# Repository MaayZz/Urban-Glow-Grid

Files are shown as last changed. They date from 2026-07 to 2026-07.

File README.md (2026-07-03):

# 🗼 Urban Glow Grid — Project Documentation

Welcome to the official repository of **Urban Glow Grid** (Team 22). This project was created to fight **"Energy Blindness"** — the invisible nature of our daily energy consumption. 

Urban Glow Grid is a **physical, interactive 1:15,000 scale model of Paris** that gamifies electrical grid management. Players act as Chief Engineers, physically manipulating dials and switches to balance grid loads, prevent blackouts, and learn key sustainable energy principles in real-time.

---

## 📸 Mockup & Hardware Overview

Below is the visual structure of the physical prototype and the challenges encountered during fabrication:

* **Paris Scale Model (Overview)**: Physical wood model split into 6 key energy zones with 3D-printed translucent landmarks (Eiffel Tower, Louvre, Arc de Triomphe) diffusing NeoPixel LED light.
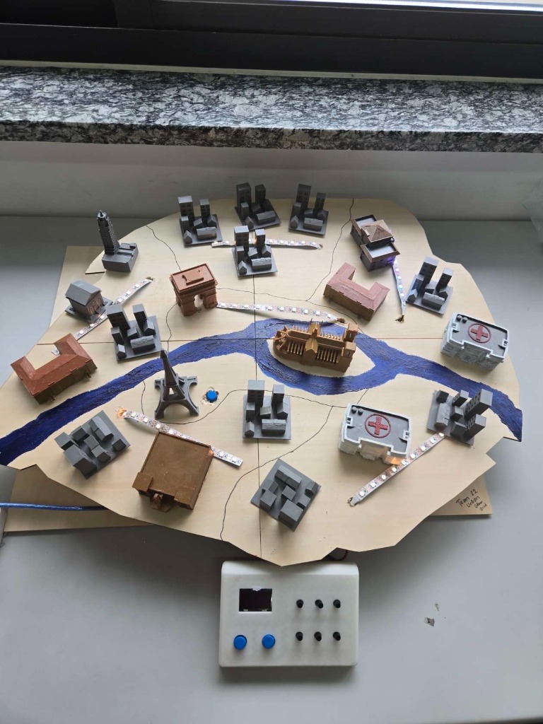
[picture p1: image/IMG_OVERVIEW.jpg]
Paris Scale Model Overview
  
* **Wiring Under the Hood (Challenges)**: A look at the electronics layer managing nearly 90 jumper wires, showing the physical complexity and loose connections we resolved by separating structural components from the circuitry.
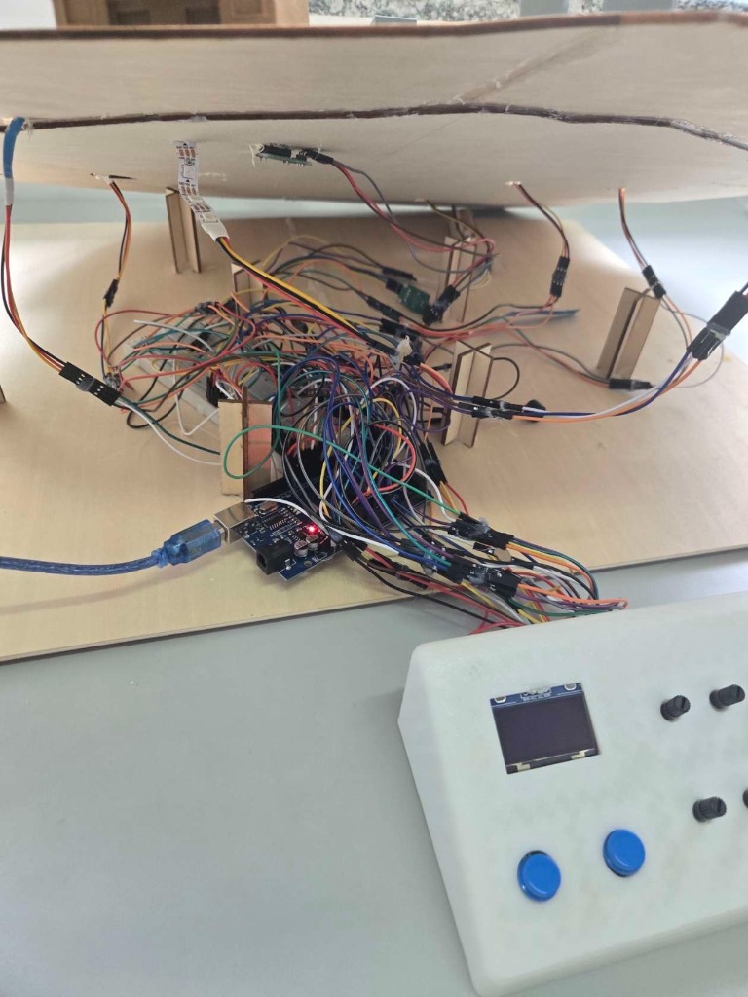
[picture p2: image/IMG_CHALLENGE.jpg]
Wiring Infrastructure Challenges
  

---

## 📂 Repository Directory Structure

To help future developers take over and scale this project, here is how the files are organized:

* `arduino/`
  * `urban_glow_grid_mega_final/`: The production code uploaded to the Arduino Mega managing inputs/outputs.
  * `mega_hardware_test/`: Simple test scripts to isolate issues with OLED, LEDs, dials, or buttons.
  * `arduino_wiring.md`: Detailed pinout mapping and electronic connection guide.
  * `wiring_guide.pdf`: Blueprints showing the circuit layout.
* `image/`: Clean folder containing project photos.

---

## 🛠 Hardware Architecture & Bill of Materials (BOM)

The physical maquette separates the **wooden layout structure** from the **electronics layer** to allow easy, non-destructive wiring iterations. 

### Key Components:
1. **Microcontroller**: Arduino Mega 2560 (selected for its high pin count to drive multiple parallel sensors/LEDs).
2. **Visual Indicators**: 6 WS2812B NeoPixel strips (underneath landmarks) + I2C SSD1306 OLED Display (shows real-time numeric load metrics).
3. **Control Interface**: 6 Potentiometers (load balancing dials) + 4 tactile Push Buttons (priority building toggles) + 1 Master Reset Button.
4. **Audio Feedback**: 8-ohm Speaker/Buzzer (emits blackout warning alarms).
5. **Physical Enclosure**: Laser-cut plywood baseboard, translucent PLA 3D-printed landmarks.

### Sourcing & Cost Breakdown (Strictly < 200 RMB)

| Component | Qty | Function | Est. Cost (RMB) |
| :--- | :---: | :--- | :---: |
| **Arduino Mega 2560** | 1 | Central Processing Unit | 45.00 |
| **WS2812B LED Strips** | 6 | Paris Zone status lights (Green/Red) | 30.00 |
| **OLED Display (I2C SSD1306)** | 1 | Real-time system display screen | 15.00 |
| **Potentiometers (Dials)** | 6 | Local load adjustment controls | 12.00 |
| **Push Buttons (Toggles)** | 4 | Priority building power overrides | 4.00 |
| **Speaker / Buzzer** | 1 | Audio blackout alarms | 5.00 |
| **Physical Materials** | — | Laser-cut plywood, 3D printing PLA, glue, screws | 80.00 |
| **TOTAL** | | | **~191.00 RMB** |

---

## 💻 Software Setup & Installation

### Arduino Code Deployment
Open the production code (`arduino/urban_glow_grid_mega_final/urban_glow_grid_mega_final.ino`) in the Arduino IDE. 

Make sure you have installed the following libraries via the Arduino Library Manager:
* **Adafruit_NeoPixel** (to control the WS2812B LEDs)
* **SSD1306Ascii** (lightweight text-only library to control the OLED screen without overloading SRAM)

Compile and upload the project onto your Arduino Mega.

---

## 🕹 Game Rules & Playbook

The game simulates a peak winter day. The player has **3 minutes** to maintain the stability of the Paris electrical grid.

1. **Balance the Grid**: Dials (potentiometers) represent zone power. When a zone turns **red** (overloaded), you must rotate the dial to decrease non-essential load.
2. **Prioritize Buildings**: Tactile buttons allow you to route power away from residential blocks to vital sectors (like hospitals or water systems) during heavy strain.
3. **Avoid Blackout**: The OLED screen shows total system capacity. If the total load exceeds 95%, the buzzer sounds a warning. If it hits 100% for more than 5 consecutive seconds, a **Blackout** is triggered: all LEDs flash red, the game resets, and you lose.
4. **Victory Condition**: Maintain system stability until the timer expires.

---

## 🚀 Future Roadmap & Developer Notes

If you are resuming this project, here are the critical steps required to turn this prototype into a commercial product:

* **Transition to Custom PCB**: The biggest hardware challenge was **Loose Connections** (wires coming loose from the breadboards due to physical vibration). Designing a dedicated Printed Circuit Board (PCB) to replace jumper wires will reduce assembly time by 95% and make the product robust enough for shipping.
* **Scale Software Architecture**: The current C++ simulation is optimized for Paris (6 zones). The code is structured modularly so you can swap out the geographic layout files and LED indices to model other cities.
* **Transition to B2B Educational Kits**: The low BOM (< 200 RMB) makes this highly profitable. Next phases should package the PCB, components, and a flat-packed wooden box as a "build-your-own smart city kit" for EdTech classrooms.

---

## 👥 Roles & Organization (Team 22)
* **CEO / Project Lead**
* **CTO / System Architecture**
* **Creative Director**
* **Hardware & Fabrication Support**

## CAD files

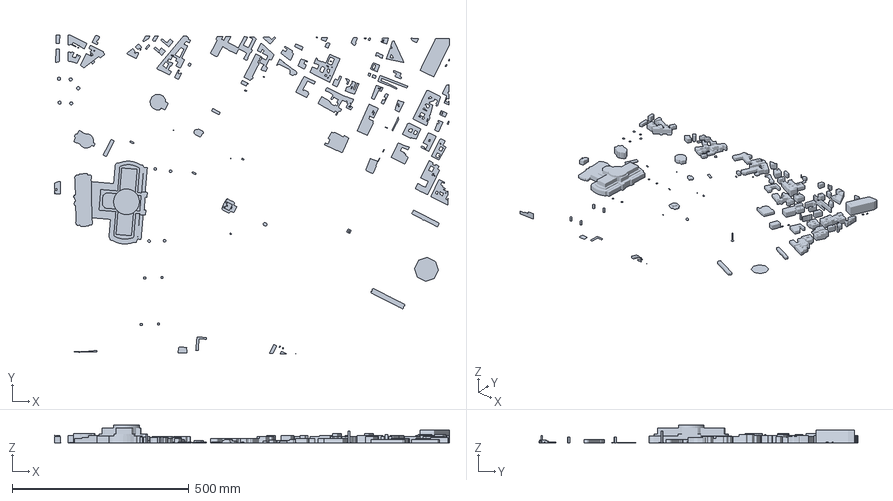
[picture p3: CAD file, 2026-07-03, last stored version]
simulation/cadmapper-paris-ile-de-france-fr.dxf
1118.6 x 903.1 x 50.0 mm

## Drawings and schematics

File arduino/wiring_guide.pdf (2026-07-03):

# Urban Glow Grid

Visualisation 3D photoréaliste du montage sur deux breadboards.

### 1. Organisation Générale des Composants

Le montage est réparti sur deux plaques d'essai (breadboards) afin de bien isoler la partie commande (basse puissance) de la partie alimentation des bandes LED (haute puissance). Cette séparation est essentielle pour éviter les parasites sur les signaux analogiques et garantir un fonctionnement stable.

Plaque d'Essai n°1 : Logique et Contrôle

MCP3008 (ADC SPI) : Placé au centre. Il reçoit les fils des 6 potentiomètres.

Guide de Câblage Visuel Officiel – Prototype Simplifié (1 Arduino Uno)

6 Potentiomètres : Alimentés en 5V et reliés aux canaux CH0 à CH5 du MCP3008.

5 Boutons Poussoirs : Câblés en direct vers l'Arduino avec la résistance interne INPUT_PULLUP.

Écran OLED SSD1306 : Relié au bus I2C matériel de l'Arduino (A4/A5).

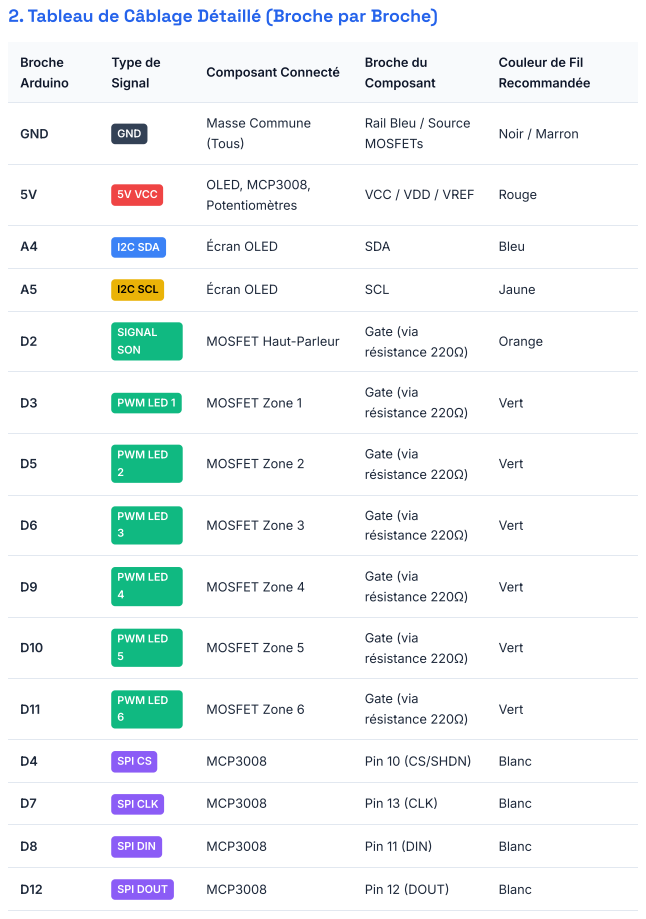
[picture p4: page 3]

2. Tableau de Câblage Détaillé (Broche par Broche)

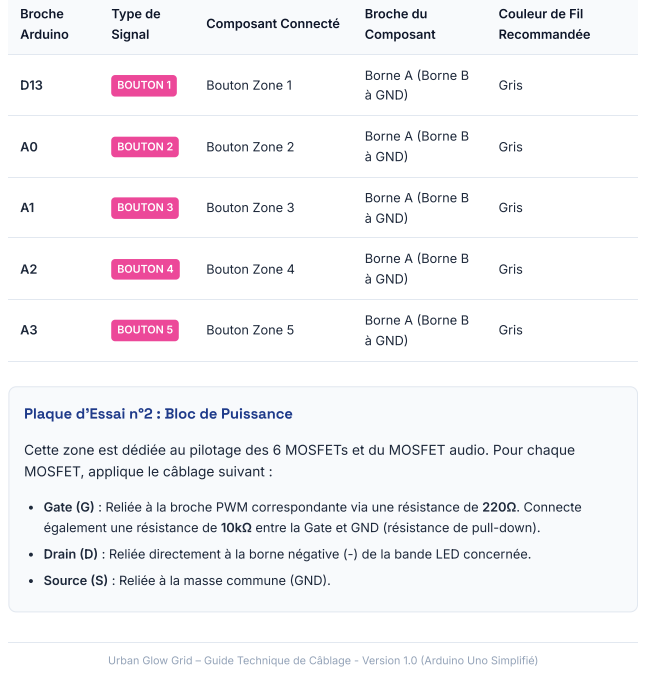
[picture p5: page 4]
Broche Arduino; Type de Signal; Composant Connecté; Broche du Composant; BOUTON 1; Bouton Zone 1; Borne A (Borne B à GND); Gris; BOUTON 2; Bouton Zone 2; BOUTON 3; Bouton Zone 3; BOUTON 4; Bouton Zone 4; BOUTON 5; Bouton Zone 5

Couleur de Fil
Recommandée

Plaque d'Essai n°2 : Bloc de Puissance

Cette zone est dédiée au pilotage des 6 MOSFETs et du MOSFET audio. Pour chaque
MOSFET, applique le câblage suivant :

Gate (G) : Reliée à la broche PWM correspondante via une résistance de 220Ω. Connecte
également une résistance de 10kΩ entre la Gate et GND (résistance de pull-down).
Drain (D) : Reliée directement à la borne négative (-) de la bande LED concernée.
Source (S) : Reliée à la masse commune (GND).

Urban Glow Grid – Guide Technique de Câblage - Version 1.0 (Arduino Uno Simplifié)

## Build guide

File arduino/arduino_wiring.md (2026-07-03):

# 🔌 Guide de Câblage & Configuration des Pins — Arduino Mega 2560

Ce document décrit les connexions électriques réelles utilisées sur le prototype physique final de **Urban Glow Grid**. Les affectations ci-dessous correspondent exactement aux définitions du code de production final (`arduino/urban_glow_grid_mega_final/urban_glow_grid_mega_final.ino`).

---

## 🎛 Tableau de Câblage Complet

| Composant Physique | Type de Signal | Pin Arduino | Mode Pin | Description |
| :--- | :--- | :--- | :--- | :--- |
| Écran OLED (1.3 pouce) | I2C (SDA / SCL) | **SDA** -> Broche D20 <br> **SCL** -> Broche D21 | Entrée / Sortie | Liaison I2C pour l'affichage de l'état du réseau |
| Potentiomètre 1 | Entrée Analogue | A0 | INPUT | Réglage de charge de la Zone 1 |
| Potentiomètre 2 | Entrée Analogue | A1 | INPUT | Réglage de charge de la Zone 2 |
| Potentiomètre 3 | Entrée Analogue | A2 | INPUT | Réglage de charge de la Zone 3 |
| Potentiomètre 4 | Entrée Analogue | A3 | INPUT | Réglage de charge de la Zone 4 |
| Potentiomètre 5 | Entrée Analogue | A4 | INPUT | Réglage de charge de la Zone 5 |
| Potentiomètre 6 | Entrée Analogue | A5 | INPUT | Réglage de charge de la Zone 6 |
| Ruban LED 17cm (Zone 1) | Sortie Digitale | Broche 2 | OUTPUT | Indicateur LED de la Zone 1 |
| Ruban LED 17cm (Zone 2) | Sortie Digitale | Broche 3 | OUTPUT | Indicateur LED de la Zone 2 |
| Ruban LED 17cm (Zone 3) | Sortie Digitale | Broche 4 | OUTPUT | Indicateur LED de la Zone 3 |
| Ruban LED 17cm (Zone 4) | Sortie Digitale | Broche 5 | OUTPUT | Indicateur LED de la Zone 4 |
| Ruban LED 17cm (Zone 5) | Sortie Digitale | Broche 6 | OUTPUT | Indicateur LED de la Zone 5 |
| Ruban LED 17cm (Zone 6) | Sortie Digitale | Broche 7 | OUTPUT | Indicateur LED de la Zone 6 |
| Ruban LED 10cm (Mon. 1) | Sortie Digitale | Broche 8 | OUTPUT | Indicateur LED du Monument 1 |
| Ruban LED 10cm (Mon. 2) | Sortie Digitale | Broche 9 | OUTPUT | Indicateur LED du Monument 2 |
| Speaker 1 | Sortie PWM | Broche 22 | OUTPUT | Haut-parleur principal (Sons système et sirènes d'alarme) |
| Speaker 2 | Sortie PWM | Broche 24 | OUTPUT | Haut-parleur secondaire (Bruits de clic / battement de cœur) |
| Bouton 1 (Start) | Entrée Digitale | Broche 26 | INPUT_PULLUP | Bouton poussoir pour lancer la partie |
| Bouton 2 (Reset) | Entrée Digitale | Broche 28 | INPUT_PULLUP | Bouton poussoir pour réinitialiser le jeu |
| Bouton 3 (Monument 1) | Entrée Digitale | Broche 30 | INPUT_PULLUP | Bouton pour activer/désactiver le Monument 1 |
| Bouton 4 (Monument 2) | Entrée Digitale | Broche 32 | INPUT_PULLUP | Bouton pour activer/désactiver le Monument 2 |

---

## 🛠 Détails du Câblage

### 1. Les 6 Potentiomètres
* Les broches extérieures sont connectées au **5V** et au **GND** de l'Arduino.
* La broche centrale (curseur) est reliée directement aux entrées analogiques `A0` à `A5` de l'Arduino Mega.

### 2. Les 4 Boutons
* Configurés en **active-low** (INPUT_PULLUP). Une borne est connectée à la broche Arduino (26/28/30/32) et l'autre est reliée à la masse commune (GND). 

### 3. Les Rubans LED (WS2812B)
* Les lignes de données (`DIN`) des 6 rubans de 17cm et des 2 rubans de 10cm sont connectées aux broches digitales `2` à `9`.
* Placez une **résistance de 330 ohms** en série entre chaque broche de sortie de l'Arduino et l'entrée du ruban LED.

### 4. L'Écran OLED (1.3 pouce)
* Branché sur le bus I2C matériel de la carte Arduino Mega 2560 (broches dédiées **SDA / D20** et **SCL / D21**).
* Alimenté via la broche **3.3V** (ou 5V selon le modèle) et GND.

### 5. Les 2 Speakers
* Les broches `22` et `24` sont reliées en série avec une **résistance de 100 ohms** à la borne positive de chaque haut-parleur. La borne négative est connectée au GND commun.

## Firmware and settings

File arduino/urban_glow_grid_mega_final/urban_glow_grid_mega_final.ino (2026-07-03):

/*
  Urban Glow Grid - Version Mega 2560 (v7 - Fenetre de Tir)
  
  Mecaniques Finales :
  - L'Accrochage (Hack) + Pannes (System Bug)
  - Vagues d'energie
  - Jauge OLED 21 caracteres Dynamique avec O et @
  - Underload (45%) et Overload (85%)
  - Target Load (Aleatoire par partie)
*/

#include <Wire.h>
#include "SSD1306Ascii.h"
#include "SSD1306AsciiWire.h"
#include <Adafruit_NeoPixel.h>

// --- Configuration OLED ---
#define I2C_ADDRESS 0x3C
SSD1306AsciiWire oled;

// --- Configuration Pins Mega ---
const int potPins[6] = {A0, A1, A2, A3, A4, A5};
const int mainStripPins[6] = {2, 3, 4, 5, 6, 7};
const int secStripPins[2] = {8, 9};

const int speaker1 = 22;
const int speaker2 = 24;

const int btnStart = 26;
const int btnReset = 28;
const int btnMonument1 = 30; 
const int btnMonument2 = 32; 

// --- Configuration Rubans LED ---
#define LEDS_MAIN 10 
#define LEDS_SEC  5  

Adafruit_NeoPixel mainStrips[6] = {
  Adafruit_NeoPixel(LEDS_MAIN, mainStripPins[0], NEO_GRB + NEO_KHZ800),
  Adafruit_NeoPixel(LEDS_MAIN, mainStripPins[1], NEO_GRB + NEO_KHZ800),
  Adafruit_NeoPixel(LEDS_MAIN, mainStripPins[2], NEO_GRB + NEO_KHZ800),
  Adafruit_NeoPixel(LEDS_MAIN, mainStripPins[3], NEO_GRB + NEO_KHZ800),
  Adafruit_NeoPixel(LEDS_MAIN, mainStripPins[4], NEO_GRB + NEO_KHZ800),
  Adafruit_NeoPixel(LEDS_MAIN, mainStripPins[5], NEO_GRB + NEO_KHZ800)
};

Adafruit_NeoPixel secStrips[2] = {
  Adafruit_NeoPixel(LEDS_SEC, secStripPins[0], NEO_GRB + NEO_KHZ800),
  Adafruit_NeoPixel(LEDS_SEC, secStripPins[1], NEO_GRB + NEO_KHZ800)
};

// --- Variables de Jeu ---
enum GameState {
  STATE_READY,
  STATE_PLAYING,
  STATE_BLACKOUT,
  STATE_TIMEOUT,
  STATE_VICTORY
};

GameState currentState = STATE_READY;

bool monument1On = false;
bool monument2On = false;
unsigned long lastDebounceTime1 = 0;
unsigned long lastDebounceTime2 = 0;
const unsigned long debounceDelay = 250;

bool zoneHooked[6] = {false};
int zoneBasePower[6] = {0}; 
unsigned long hookFlashTime[6] = {0}; 

int zonePower[6] = {0}; 
int lastZonePower[6] = {-1, -1, -1, -1, -1, -1};
int lastVisualState[6] = {0}; 
bool zoneActive[6] = {false};

unsigned long lastBreakdownTime = 0;
unsigned long nextBreakdownDelay = 15000;

bool isOverloaded = false;
bool isUnderloaded = false;
unsigned long overloadStartTime = 0;
unsigned long underloadStartTime = 0;
unsigned long lastHeartbeat = 0;
bool isVictoryTimerRunning = false;
unsigned long victoryStartTime = 0;

const unsigned long GAME_DURATION_MS = 180000; 
unsigned long gameStartTime = 0;
long finalScore = 0;
long finalTimeRemaining = 0;

const int MIN_POWER_TO_ACTIVATE = 15; 
const int UNDERLOAD_THRESHOLD = 30;   // 30% MIN
const int OVERLOAD_THRESHOLD = 85;    // 85% MAX
const int DANGER_DELAY = 2500;        
const int VICTORY_DELAY = 5000;       

// La Cible (Fenêtre de Tir)
int targetMin = 60;
int targetMax = 65;

unsigned long lastOledUpdate = 0;
unsigned long lastSirenTime = 0;
bool sirenHigh = false;
String blackoutReason = "";

void setup() {
  Serial.begin(9600);
  randomSeed(analogRead(A15)); 
  
  Wire.begin();
  oled.begin(&Adafruit128x64, I2C_ADDRESS);
  oled.setFont(System5x7);
  
  pinMode(btnStart, INPUT_PULLUP);
  pinMode(btnReset, INPUT_PULLUP);
  pinMode(btnMonument1, INPUT_PULLUP);
  pinMode(btnMonument2, INPUT_PULLUP);
  
  pinMode(speaker1, OUTPUT);
  pinMode(speaker2, OUTPUT);

  for(int i=0; i<6; i++) {
    mainStrips[i].begin();
    mainStrips[i].show();
  }
  for(int i=0; i<2; i++) {
    secStrips[i].begin();
    secStrips[i].show();
  }

  showReadyScreen();
}

void loop() {
  if (digitalRead(btnReset) == LOW) {
    tone(speaker1, 300, 200);
    delay(200);
    resetGame();
  }

  switch(currentState) {
    case STATE_READY:
      if (digitalRead(btnStart) == LOW) {
        attemptStartGame();
      }
      playBreathingAnimation();
      break;
      
    case STATE_PLAYING:
      playGame();
      break;
      
    case STATE_BLACKOUT:
      playBlackoutAnimation();
      break;

    case STATE_TIMEOUT:
      playTimeoutAnimation();
      break;
      
    case STATE_VICTORY:
      playVictoryAnimation();
      break;
  }
}

// ==========================================
// FONCTIONS DE LOGIQUE DE JEU
// ==========================================

void attemptStartGame() {
  // Generation de la Cible (Delta strict de 5%)
  targetMin = random(60, 76);
  targetMax = targetMin + 5; 
  
  for (int i = 0; i < 6; i++) {
    zoneHooked[i] = false;
    zoneBasePower[i] = random(20, 85); 
    hookFlashTime[i] = 0;
  }

  tone(speaker1, 1000, 100);
  delay(150);
  tone(speaker1, 1500, 300);
  
  currentState = STATE_PLAYING;
  monument1On = false;
  monument2On = false;
  isOverloaded = false;
  isUnderloaded = false;
  isVictoryTimerRunning = false;
  gameStartTime = millis();
  
  lastBreakdownTime = millis();
  nextBreakdownDelay = random(15000, 25000); 

  for(int i=0; i<6; i++) {
    lastZonePower[i] = -1;
    lastVisualState[i] = -1;
  }

  turnOffAllStrips();
  oled.clear(); 
  updateOledPlaying(0, false, false, 0, GAME_DURATION_MS, false);
}

void resetGame() {
  currentState = STATE_READY;
  turnOffAllStrips();
  showReadyScreen();
}

void playGame() {
  unsigned long currentMillis = millis();

  // 1. Chronometre
  long timeElapsed = currentMillis - gameStartTime;
  long timeRemaining = GAME_DURATION_MS - timeElapsed;

  if (timeRemaining <= 0) {
    triggerTimeout();
    return;
  }

  // 2. Panne Aleatoire (System Bug)
  if (currentMillis - lastBreakdownTime > nextBreakdownDelay) {
    int zoneToBreak = random(0, 6);
    zoneHooked[zoneToBreak] = false;
    zoneBasePower[zoneToBreak] = random(20, 85); 
    tone(speaker1, 200, 400); 
    
    lastBreakdownTime = currentMillis;
    nextBreakdownDelay = random(15000, 30000); 
  }

  // 3. Boutons Monuments
  if (digitalRead(btnMonument1) == LOW && (currentMillis - lastDebounceTime1 > debounceDelay)) {
    monument1On = !monument1On; 
    lastDebounceTime1 = currentMillis;
    if (monument1On) {
      tone(speaker2, 1200, 100);
      setSecStripColor(0, 0, 255, 150); 
    } else {
      tone(speaker2, 600, 100);
      setSecStripColor(0, 0, 0, 0); 
    }
  }
  
  if (digitalRead(btnMonument2) == LOW && (currentMillis - lastDebounceTime2 > debounceDelay)) {
    monument2On = !monument2On; 
    lastDebounceTime2 = currentMillis;
    if (monument2On) {
      tone(speaker2, 1200, 100);
      setSecStripColor(1, 0, 255, 150); 
    } else {
      tone(speaker2, 600, 100);
      setSecStripColor(1, 0, 0, 0); 
    }
  }

  // 4. Vague d'Energie (Tres Ralentie et Adoucie)
  int waveOffset = (sin(currentMillis / 8000.0) * 12.0) + (sin(currentMillis / 3500.0) * 8.0);

  // 5. Mise a jour des zones
  int totalPower = 0;
  int activeZonesCount = 0;
  bool allHooked = true;

  for (int i = 0; i < 6; i++) {
    int potRaw = analogRead(potPins[i]);
    int potPercent = map(potRaw, 0, 1023, 0, 100);
    
    if (!zoneHooked[i]) {
      allHooked = false;
      if (abs(potPercent - zoneBasePower[i]) <= 5) {
        zoneHooked[i] = true;
        hookFlashTime[i] = currentMillis; 
        tone(speaker2, 1000 + (i * 200), 150); 
      }
    } else {
      zoneBasePower[i] = potPercent;
    }

    int finalPower = zoneBasePower[i] + waveOffset;
    finalPower = constrain(finalPower, 0, 100); 
    
    zonePower[i] = finalPower;
    
    if (finalPower > MIN_POWER_TO_ACTIVATE) {
      zoneActive[i] = true;
      activeZonesCount++;
    } else {
      zoneActive[i] = false;
    }

    totalPower += finalPower;

    bool isFlashingGreen = (currentMillis - hookFlashTime[i] < 300) && zoneHooked[i];
    bool isBroken = !zoneHooked[i];
    
    int currentVisualState = 0;
    if (isFlashingGreen) currentVisualState = 1;
    else if (isBroken) currentVisualState = ((currentMillis / 150) % 2 == 0) ? 2 : 3;

    if (finalPower != lastZonePower[i] || currentVisualState != lastVisualState[i]) {
      updateMainStrip(i, finalPower, isFlashingGreen, isBroken, currentMillis);
      lastZonePower[i] = finalPower;
      lastVisualState[i] = currentVisualState;
    }
  }

  int averageLoad = totalPower / 6;

  // 6. HEARTBEAT Audio
  int stressLevel = 0; 
  if (averageLoad < 50) stressLevel = map(averageLoad, 50, UNDERLOAD_THRESHOLD, 0, 100);
  else if (averageLoad > 80) stressLevel = map(averageLoad, 80, OVERLOAD_THRESHOLD, 0, 100);
  
  if (timeRemaining < 30000) {
    int timeStress = map(timeRemaining, 30000, 0, 0, 100);
    stressLevel = max(stressLevel, timeStress);
  }
  
  if (stressLevel > 0 && !isOverloaded && !isUnderloaded) {
    stressLevel = constrain(stressLevel, 0, 100);
    int beatInterval = map(stressLevel, 0, 100, 1500, 250);
    if (currentMillis - lastHeartbeat > beatInterval) {
      lastHeartbeat = currentMillis;
      tone(speaker2, 80, 50); 
    }
  }

  // 7. OVERLOAD (> 85%)
  if (averageLoad > OVERLOAD_THRESHOLD) {
    if (!isOverloaded) {
      isOverloaded = true;
      overloadStartTime = currentMillis;
      isVictoryTimerRunning = false;
    }
    if (currentMillis - lastSirenTime > 300) {
      lastSirenTime = currentMillis;
      sirenHigh = !sirenHigh;
      if (sirenHigh) tone(speaker1, 800, 200);
      else tone(speaker1, 600, 200);
    }
    if (currentMillis - overloadStartTime > DANGER_DELAY) {
      triggerBlackout("OVERLOAD MAX");
      return;
    }
  } else {
    isOverloaded = false;
  }

  // 8. UNDERLOAD (< 45%)
  if (averageLoad < UNDERLOAD_THRESHOLD) {
    if (!isUnderloaded) {
      isUnderloaded = true;
      underloadStartTime = currentMillis;
      isVictoryTimerRunning = false;
    }
    if (currentMillis - lastSirenTime > 400) {
      lastSirenTime = currentMillis;
      sirenHigh = !sirenHigh;
      if (sirenHigh) tone(speaker1, 300, 300);
      else tone(speaker1, 200, 300);
    }
    if (currentMillis - underloadStartTime > DANGER_DELAY) {
      triggerBlackout("UNDERLOADED");
      return;
    }
  } else {
    isUnderloaded = false;
  }

  // 9. Victoire (Dans la Fenetre !)
  bool isTargetHit = (averageLoad >= targetMin && averageLoad <= targetMax);

  if (activeZonesCount == 6 && !isOverloaded && !isUnderloaded && allHooked && isTargetHit) {
    if (!isVictoryTimerRunning) {
      isVictoryTimerRunning = true;
      victoryStartTime = currentMillis;
    }
    if (currentMillis - victoryStartTime > VICTORY_DELAY) {
      finalTimeRemaining = timeRemaining;
      finalScore = timeRemaining / 10; 
      triggerVictory();
      return;
    }
  } else {
    isVictoryTimerRunning = false;
  }

  // 10. OLED
  if (currentMillis - lastOledUpdate > 200) {
    updateOledPlaying(averageLoad, isOverloaded, isUnderloaded, currentMillis, timeRemaining, !allHooked);
    lastOledUpdate = currentMillis;
  }
}

void triggerBlackout(String reason) {
  currentState = STATE_BLACKOUT;
  blackoutReason = reason;
  turnOffAllStrips();
  tone(speaker1, 100, 500);
  tone(speaker2, 80, 800);
  
  oled.clear();
  oled.set1X();
  oled.setCursor(0, 1);
  oled.print("   SYSTEM BLACKOUT   ");
  oled.setCursor(0, 3);
  oled.print("FATAL: "); oled.print(reason);
  oled.setCursor(0, 6);
  oled.print("  >> PRESS RESET <<  ");
}

void triggerTimeout() {
  currentState = STATE_TIMEOUT;
  turnOffAllStrips();
  
  tone(speaker1, 300, 400); delay(450);
  tone(speaker1, 250, 400); delay(450);
  tone(speaker1, 200, 800);
  
  oled.clear();
  oled.set1X();
  oled.setCursor(0, 2);
  oled.print("    TIME IS UP !     ");
  oled.setCursor(0, 5);
  oled.print("  >> PRESS RESET <<  ");
}

void triggerVictory() {
  currentState = STATE_VICTORY;
  
  int melody[] = {523, 659, 784, 1046}; 
  for (int i=0; i<4; i++) {
    tone(speaker1, melody[i], 150);
    delay(200);
  }
  
  oled.clear();
  oled.set1X();
  oled.setCursor(0, 0);
  oled.print(" *** VICTORY ! ***   ");
  oled.setCursor(0, 2);
  oled.print("SCORE: "); oled.print(finalScore); oled.print(" PTS");
  
  int s = (finalTimeRemaining / 1000) % 60;
  int m = (finalTimeRemaining / 1000) / 60;
  oled.setCursor(0, 3);
  oled.print("TIME LEFT: 0"); oled.print(m); oled.print(":");
  if (s<10) oled.print("0"); oled.print(s);
  
  oled.setCursor(0, 6);
  oled.print("  >> PRESS RESET <<  ");
}

// ==========================================
// FONCTIONS D'AFFICHAGE ET D'ANIMATION
// ==========================================

void showReadyScreen() {
  oled.clear();
  oled.set1X();
  oled.setCursor(0, 0);
  oled.println("=====================");
  oled.println("   URBAN GLOW GRID   ");
  oled.println("=====================");
  oled.println("");
  oled.println("   STATUS : ONLINE   ");
  oled.println("");
  oled.println("  >> PRESS START <<  ");
}

void updateOledPlaying(int load, bool overload, bool underload, unsigned long currentMillis, long timeRemaining, bool needsHooking) {
  int secondsRemaining = timeRemaining / 1000;
  int m = secondsRemaining / 60;
  int s = secondsRemaining % 60;

  oled.set1X();
  
  // LIGNE 0 : Temps et Load 
  oled.setCursor(0, 0);
  oled.print("T: 0"); oled.print(m); oled.print(":");
  if (s < 10) oled.print("0"); oled.print(s);
  oled.print("   LOAD: ");
  if(load < 100) oled.print(" ");
  if(load < 10) oled.print(" ");
  oled.print(load);
  oled.print("%");

  // LIGNE 2 : JAUGE VISUELLE INTELLIGENTE
  String bar = "[";
  int fillEnd = map(load, 0, 100, 1, 19);
  int underPos = map(UNDERLOAD_THRESHOLD, 0, 100, 1, 19);
  int overPos = map(OVERLOAD_THRESHOLD, 0, 100, 1, 19);
  int tMinPos = map(targetMin, 0, 100, 1, 19);
  int tMaxPos = map(targetMax, 0, 100, 1, 19);

  for (int i = 1; i <= 19; i++) {
    if (i >= tMinPos && i <= tMaxPos) {
      if (i <= fillEnd) bar += "@"; // Cible atteinte (pleine)
      else bar += "O"; // Cible vide
    } else {
      if (i <= fillEnd) bar += "=";
      else if (i == underPos || i == overPos) bar += "|";
      else bar += "-";
    }
  }
  bar += "]";
  oled.setCursor(0, 2);
  oled.print(bar);

  // LIGNE 4 : Alertes ou Cible
  oled.setCursor(0, 4);
  if (overload) {
    if ((currentMillis / 250) % 2 == 0) oled.print("! OVERLOAD CRITICAL !");
    else oled.print("                     ");
  } else if (underload) {
    if ((currentMillis / 250) % 2 == 0) oled.print("! UNDERLOAD WARNING !");
    else oled.print("                     ");
  } else if (needsHooking) {
    if ((currentMillis / 300) % 2 == 0) oled.print("  [ SYSTEM BUG ! ]   ");
    else oled.print("                     ");
  } else {
    oled.print("TARGET: "); oled.print(targetMin); oled.print("% - "); 
    oled.print(targetMax); oled.print("%    ");
  }

  // LIGNE 6 : Info Contextuelle
  oled.setCursor(0, 6);
  if (overload || underload) {
    oled.print("DANGER: FIX GRID NOW!");
  } else if (isVictoryTimerRunning) {
    oled.print("STABILIZING... HOLD! ");
  } else if (needsHooking) {
    oled.print("Fix System Bug !     ");
  } else {
    oled.print("Hit Target to Win !  ");
  }
}

void updateMainStrip(int stripIndex, int powerPercent, bool isFlashingGreen, bool isBroken, unsigned long currentMillis) {
  uint32_t color;

  if (isFlashingGreen) {
    color = mainStrips[stripIndex].Color(0, 255, 0); 
  } else if (isBroken) {
    if ((currentMillis / 150) % 2 == 0) color = mainStrips[stripIndex].Color(255, 0, 0);
    else color = mainStrips[stripIndex].Color(0, 0, 0);
  } else {
    int brightness = map(powerPercent, 0, 100, 0, 255);
    if (powerPercent < 5) {
      color = mainStrips[stripIndex].Color(0, 0, 0); 
    } else if (powerPercent > 95) {
      color = mainStrips[stripIndex].Color(255, 255, 255);
    } else {
      color = mainStrips[stripIndex].Color(brightness, brightness*0.7, brightness*0.1);
    }
  }

  for (int i = 0; i < LEDS_MAIN; i++) {
    mainStrips[stripIndex].setPixelColor(i, color);
  }
  mainStrips[stripIndex].show();
}

void setSecStripColor(int stripIndex, int r, int g, int b) {
  uint32_t color = secStrips[stripIndex].Color(r, g, b);
  for (int i=0; i<LEDS_SEC; i++) {
    secStrips[stripIndex].setPixelColor(i, color);
  }
  secStrips[stripIndex].show();
}

void turnOffAllStrips() {
  for(int i=0; i<6; i++) {
    mainStrips[i].clear();
    mainStrips[i].show();
  }
  for(int i=0; i<2; i++) {
    secStrips[i].clear();
    secStrips[i].show();
  }
}

void playBreathingAnimation() {
  static unsigned long lastUpdate = 0;
  if(millis() - lastUpdate < 50) return;
  lastUpdate = millis();

  unsigned long t = millis();
  int brightness = (sin(t / 500.0) + 1.0) * 30; 
  for(int i=0; i<6; i++) {
    for (int j=0; j<LEDS_MAIN; j++) {
      mainStrips[i].setPixelColor(j, mainStrips[i].Color(brightness, brightness*0.5, 0));
    }
    mainStrips[i].show();
  }
}

void playBlackoutAnimation() {
  static unsigned long lastUpdate = 0;
  if(millis() - lastUpdate < 250) return;
  lastUpdate = millis();

  if ((millis() / 500) % 2 == 0) {
    for(int i=0; i<6; i++) {
      for (int j=0; j<LEDS_MAIN; j++) mainStrips[i].setPixelColor(j, 255, 0, 0);
      mainStrips[i].show();
    }
  } else {
    turnOffAllStrips();
  }
}

void playTimeoutAnimation() {
  static unsigned long lastUpdate = 0;
  if(millis() - lastUpdate < 250) return;
  lastUpdate = millis();

  if ((millis() / 500) % 2 == 0) {
    for(int i=0; i<6; i++) {
      for (int j=0; j<LEDS_MAIN; j++) mainStrips[i].setPixelColor(j, 0, 0, 255); 
      mainStrips[i].show();
    }
  } else {
    turnOffAllStrips();
  }
}

void playVictoryAnimation() {
  static unsigned long lastUpdate = 0;
  if(millis() - lastUpdate < 20) return;
  lastUpdate = millis();

  long firstPixelHue = millis() * 256; 
  for(int i=0; i<6; i++) {
    for(int j=0; j<LEDS_MAIN; j++) {
      int pixelHue = firstPixelHue + (j * 65536L / LEDS_MAIN);
      mainStrips[i].setPixelColor(j, mainStrips[i].gamma32(mainStrips[i].ColorHSV(pixelHue)));
    }
    mainStrips[i].show();
  }
  for(int i=0; i<2; i++) {
    for(int j=0; j<LEDS_SEC; j++) {
      int pixelHue = firstPixelHue + (j * 65536L / LEDS_SEC);
      secStrips[i].setPixelColor(j, secStrips[i].gamma32(secStrips[i].ColorHSV(pixelHue)));
    }
    secStrips[i].show();
  }
}

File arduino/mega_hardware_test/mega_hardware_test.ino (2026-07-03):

#include <Wire.h>
#include "SSD1306Ascii.h"
#include "SSD1306AsciiWire.h"
#include <Adafruit_NeoPixel.h>

// --- Configuration OLED ---
#define I2C_ADDRESS 0x3C
SSD1306AsciiWire oled;

// --- Configuration LED ---
// On met 10 LEDs par défaut pour le test (modifiable)
#define LEDS_PER_STRIP 10 
const int stripPins[6] = {2, 3, 4, 5, 6, 7};
Adafruit_NeoPixel strip1(LEDS_PER_STRIP, stripPins[0], NEO_GRB + NEO_KHZ800);
Adafruit_NeoPixel strip2(LEDS_PER_STRIP, stripPins[1], NEO_GRB + NEO_KHZ800);
Adafruit_NeoPixel strip3(LEDS_PER_STRIP, stripPins[2], NEO_GRB + NEO_KHZ800);
Adafruit_NeoPixel strip4(LEDS_PER_STRIP, stripPins[3], NEO_GRB + NEO_KHZ800);
Adafruit_NeoPixel strip5(LEDS_PER_STRIP, stripPins[4], NEO_GRB + NEO_KHZ800);
Adafruit_NeoPixel strip6(LEDS_PER_STRIP, stripPins[5], NEO_GRB + NEO_KHZ800);
Adafruit_NeoPixel* strips[6] = {&strip1, &strip2, &strip3, &strip4, &strip5, &strip6};

// --- Configuration Potentiomètres ---
const int potPins[6] = {A0, A1, A2, A3, A4, A5};

// --- Configuration Boutons ---
const int btnStart = 26;
const int btnReset = 28;

// --- Configuration Speakers ---
const int speaker1 = 22;
const int speaker2 = 24;

void setup() {
  Serial.begin(9600);
  
  // Initialisation I2C et OLED
  Wire.begin();
  oled.begin(&Adafruit128x64, I2C_ADDRESS);
  oled.setFont(System5x7);
  oled.clear();
  oled.println("=== TEST HARDWARE ===");
  oled.println("Test Audio...");

  // Initialisation Boutons
  pinMode(btnStart, INPUT_PULLUP);
  pinMode(btnReset, INPUT_PULLUP);

  // Initialisation Speakers
  pinMode(speaker1, OUTPUT);
  pinMode(speaker2, OUTPUT);

  // Initialisation des 6 rubans LED
  for (int i = 0; i < 6; i++) {
    strips[i]->begin();
    strips[i]->show(); // Tout éteindre au démarrage
  }

  // Petit test audio au démarrage
  tone(speaker1, 1000, 200);
  delay(300);
  tone(speaker2, 1500, 200);
  delay(300);
  
  oled.clear();
  oled.println("=== TEST HARDWARE ===");
  oled.println("Tourne les pots !");
}

void loop() {
  bool needsUpdate = false;
  static unsigned long lastOledUpdate = 0;
  
  // 1. Tester les boutons
  if (digitalRead(btnStart) == LOW) {
    tone(speaker1, 800, 100);
    oled.setCursor(0, 3);
    oled.print("Bouton: START presse ");
    delay(200); // Anti-rebond basique
  }
  
  if (digitalRead(btnReset) == LOW) {
    tone(speaker2, 400, 100);
    oled.setCursor(0, 3);
    oled.print("Bouton: RESET presse ");
    delay(200);
  }

  // 2. Lire les potentiomètres et allumer les LEDs
  for (int i = 0; i < 6; i++) {
    int potValue = analogRead(potPins[i]); // Valeur de 0 à 1023
    
    // On convertit la valeur du potentiomètre (0-1023) en luminosité (0-255)
    int brightness = map(potValue, 0, 1023, 0, 255);
    
    // Si la valeur est très faible, on éteint
    if (brightness < 10) brightness = 0;

    // Allumer tout le ruban avec cette luminosité (en blanc chaud/jaune pour tester)
    for (int j = 0; j < LEDS_PER_STRIP; j++) {
      strips[i]->setPixelColor(j, strips[i]->Color(brightness, brightness * 0.7, brightness * 0.2));
    }
    strips[i]->show();
  }

  // Mettre à jour l'OLED toutes les 500ms avec les valeurs des 2 premiers potentiomètres pour vérifier
  if (millis() - lastOledUpdate > 500) {
    oled.setCursor(0, 5);
    oled.print("Pot 1: "); oled.print(analogRead(potPins[0])); oled.print("   ");
    oled.setCursor(0, 6);
    oled.print("Pot 6: "); oled.print(analogRead(potPins[5])); oled.print("   ");
    lastOledUpdate = millis();
  }
}

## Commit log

2026-07-03 Initial commit: Urban Glow Grid project code and documentation
    [Team22_UrbanGlowGrid_Material_List copy.xlsx, cadmapper-paris-ile-de-france-fr.dxf]
2026-07-03 Add detailed Arduino Mega wiring documentation
2026-07-03 Cleanup repository: keep only README, code, wiring, and images
    [Team22_UrbanGlowGrid_Material_List copy.xlsx, cadmapper-paris-ile-de-france-fr.dxf]
2026-07-03 Update wiring guide: map real final components used in physical mockup
2026-07-03 Configure wiring and BOM tables with exact components requested
2026-07-03 Update wiring guide: apply requested table format exactly
2026-07-03 Update wiring guide: merge OLED SDA/SCL rows to avoid confusion about screen quantity
